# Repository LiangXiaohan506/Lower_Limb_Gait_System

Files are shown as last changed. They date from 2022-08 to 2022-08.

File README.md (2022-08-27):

# Lower_Limb_Gait_System
下肢步态数据采集系统

本项目针对医学康复中的下肢外骨骼步态规划困难、难以实现个性化、控制反馈信息不完善等问题，研发了可穿戴便携式步态数据采集系统。

使用鞋垫形的柔性阵列压力传感器采集静态或运动态的足底压力，使用六轴传感器（3轴陀螺仪+3轴加速度计）采集踝关节、足尖、膝关节、髋关节静态或运动态的关节角度信息。通过优化的并行式采集电路和采集算法，实现压力分布数据的快速采集，采集到的数据可以通过WIFI或串口上传到自主开发的上位机，在上位中进行数据显示和保存。

同时为了穿戴的舒适性，本项目为数据采集模块设计了符合人体工学的外壳。

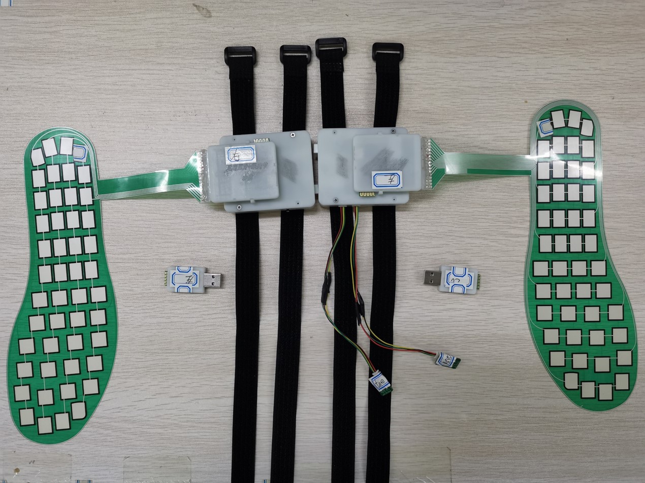
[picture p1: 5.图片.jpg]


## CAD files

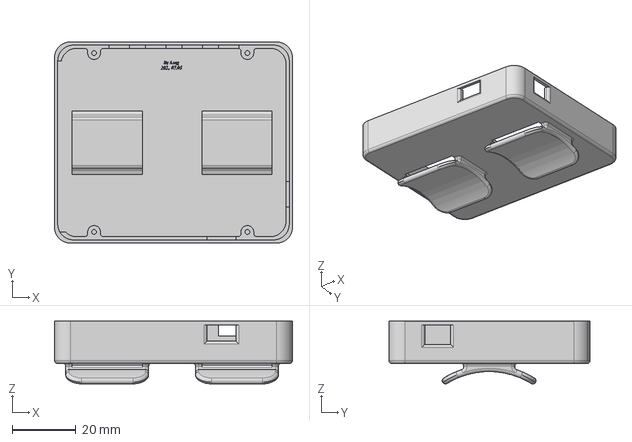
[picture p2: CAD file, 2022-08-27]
3.PP-Model/电源模块-底-V2.0-右.step
74.5 x 63.0 x 19.7 mm

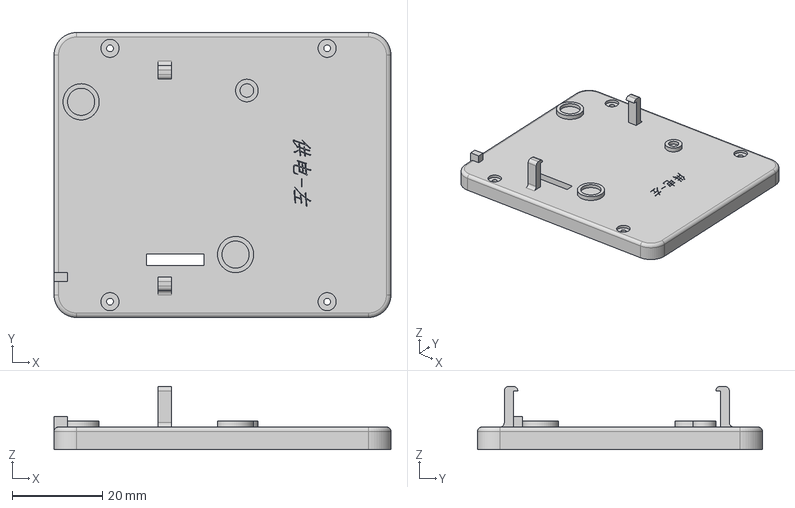
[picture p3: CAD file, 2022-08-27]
3.PP-Model/电源模块-盖-V2.0-左.step
74.5 x 63.0 x 14.0 mm

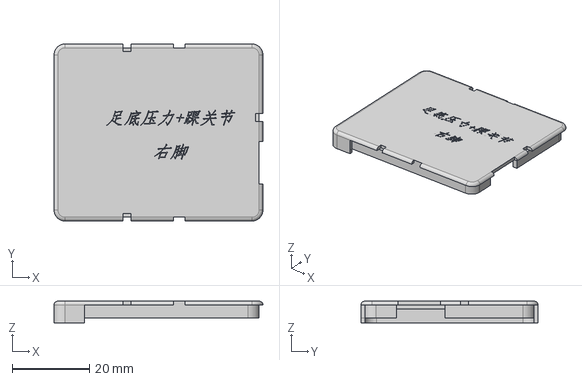
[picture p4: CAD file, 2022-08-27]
3.PP-Model/足底外壳-盖-V2.0-右.step
54.0 x 45.8 x 5.60 mm

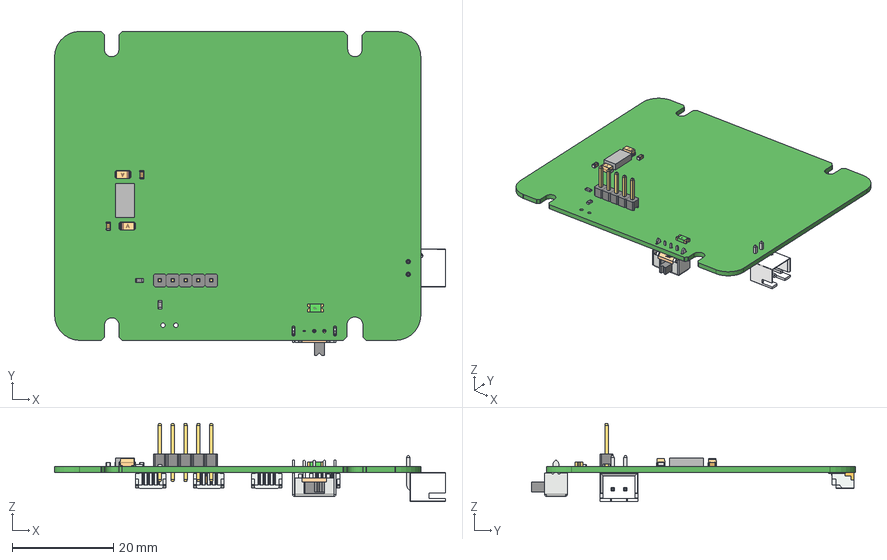
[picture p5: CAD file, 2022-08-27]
3.PP-Model/电源板.step
77.1 x 64.0 x 15.4 mm
Board
Extruded
SK-12D07
LOGO?0.75
R_0603 x 2
LOGO? x 13
SH07W_KORP x 4
SHXX_PIN x 4
SHXX_PIN_1 x 4
SHXX_PIN_2 x 4
SHXX_PIN_4 x 4
SHXX_PIN_5 x 4
SHXX_PIN_6 x 4
HDR2.54-1P x 5
FU_1206
CD_A(3216) x 2
C_0603 x 2
XH2.54-2P_H

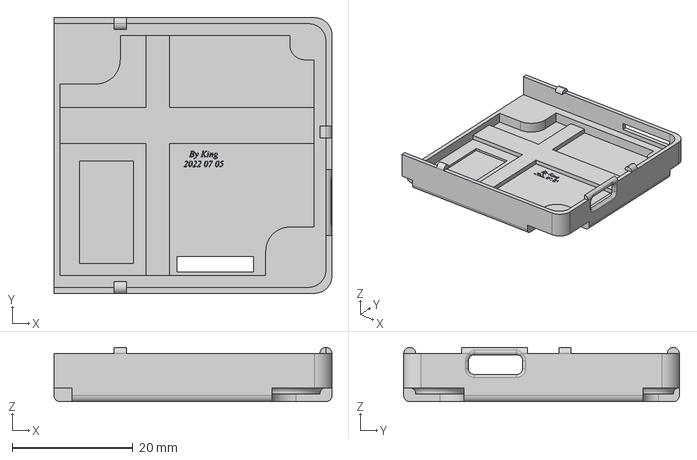
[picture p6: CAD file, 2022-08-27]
3.PP-Model/足底外壳-底-V2.0-左.step
46.1 x 45.8 x 9.00 mm

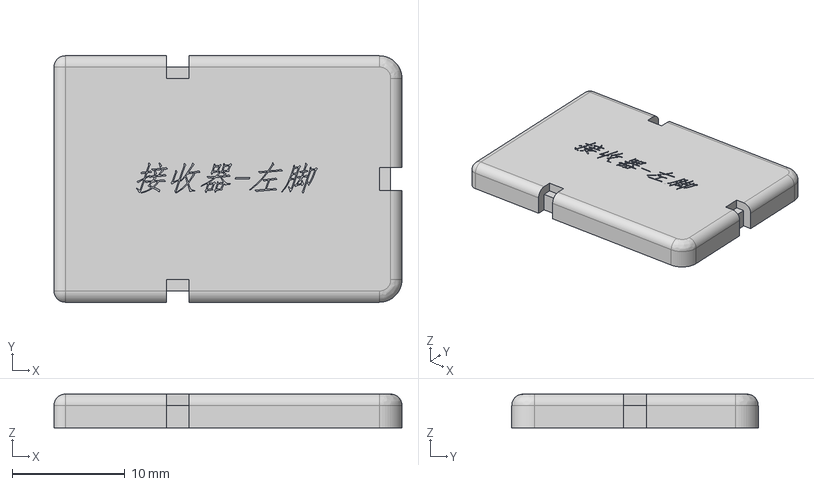
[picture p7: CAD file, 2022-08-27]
3.PP-Model/接收器_盖_左.step
30.9 x 21.9 x 3.00 mm

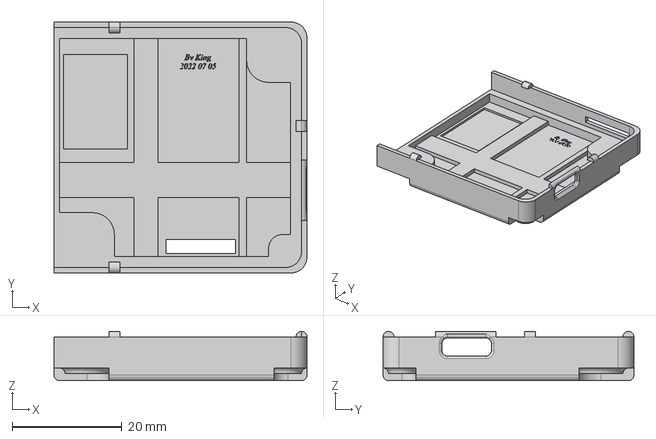
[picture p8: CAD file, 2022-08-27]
3.PP-Model/足底外壳-底-V2.0-右.step
46.1 x 45.8 x 9.00 mm

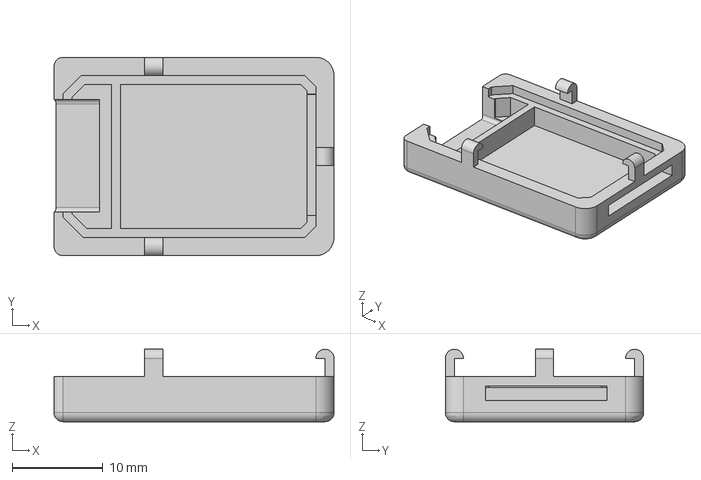
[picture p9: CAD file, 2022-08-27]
3.PP-Model/接收器_底.step
30.9 x 21.9 x 8.00 mm

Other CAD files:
3.PP-Model/足底外壳-盖-V2.0-左.step
3.PP-Model/接收器_盖_右.step
3.PP-Model/电源模块-底-V2.0-左.step
3.PP-Model/电源模块-盖-V2.0-右.step

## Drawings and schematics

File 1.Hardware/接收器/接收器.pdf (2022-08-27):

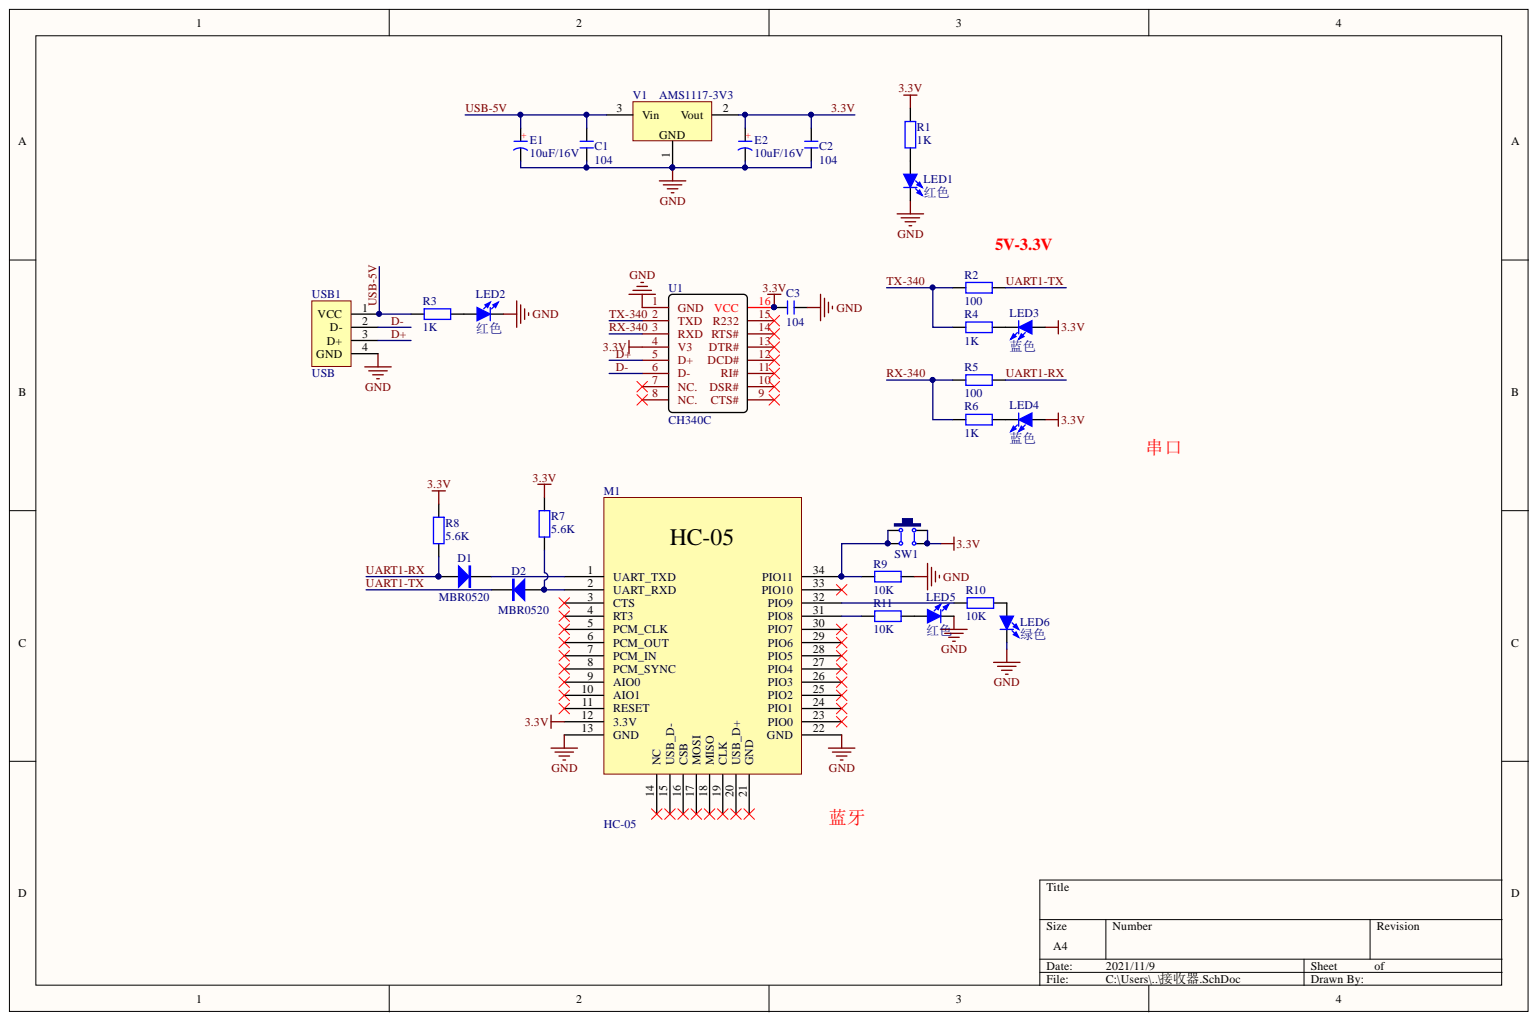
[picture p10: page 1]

UART_RXD 2
RT3 4 | R11

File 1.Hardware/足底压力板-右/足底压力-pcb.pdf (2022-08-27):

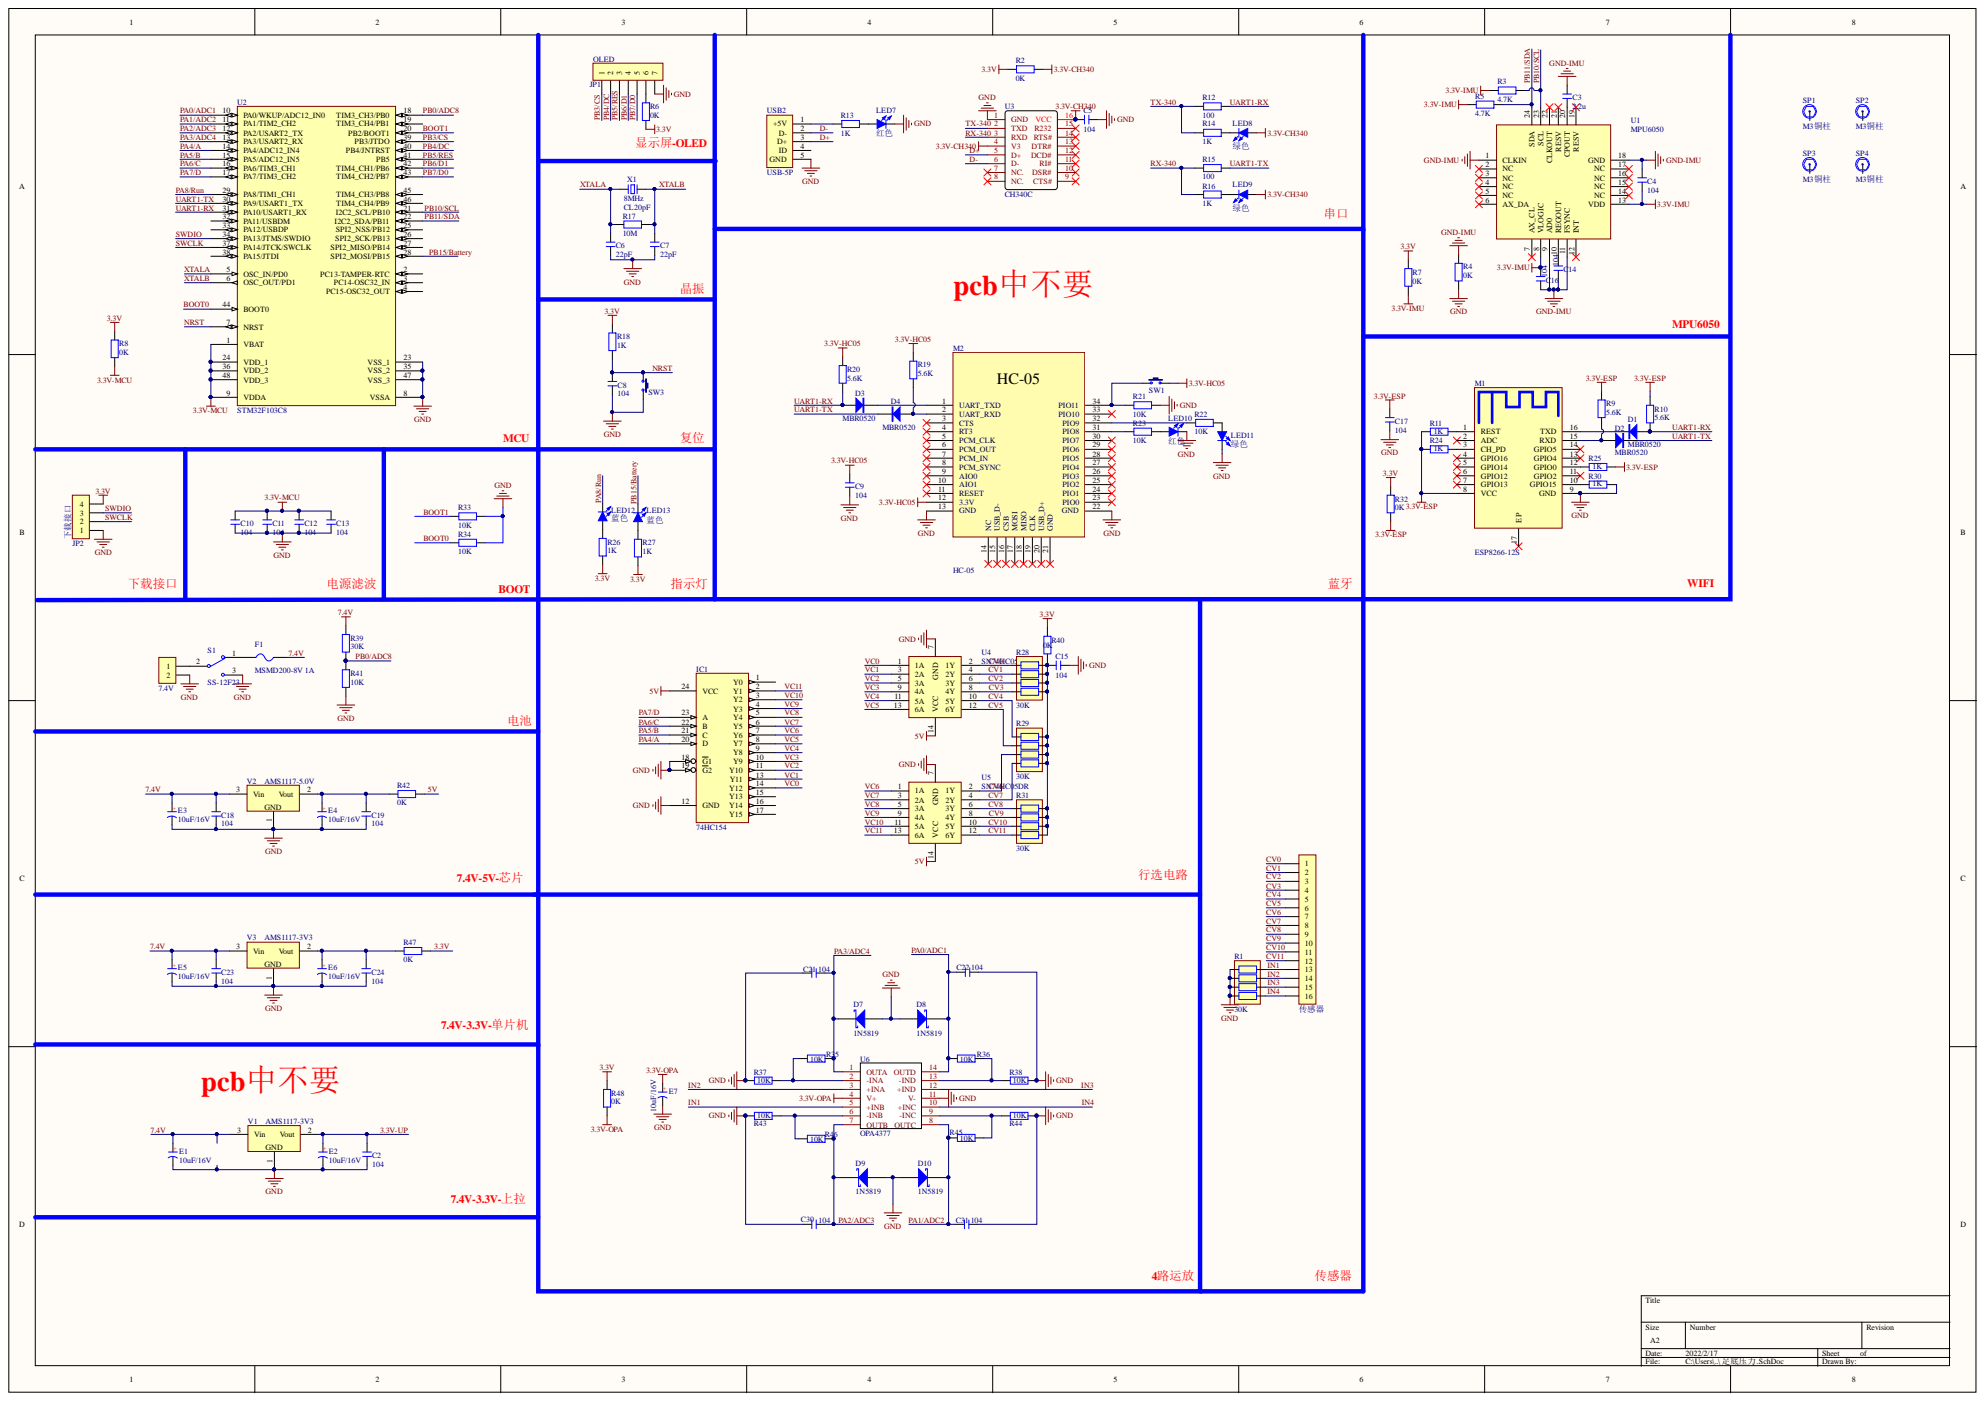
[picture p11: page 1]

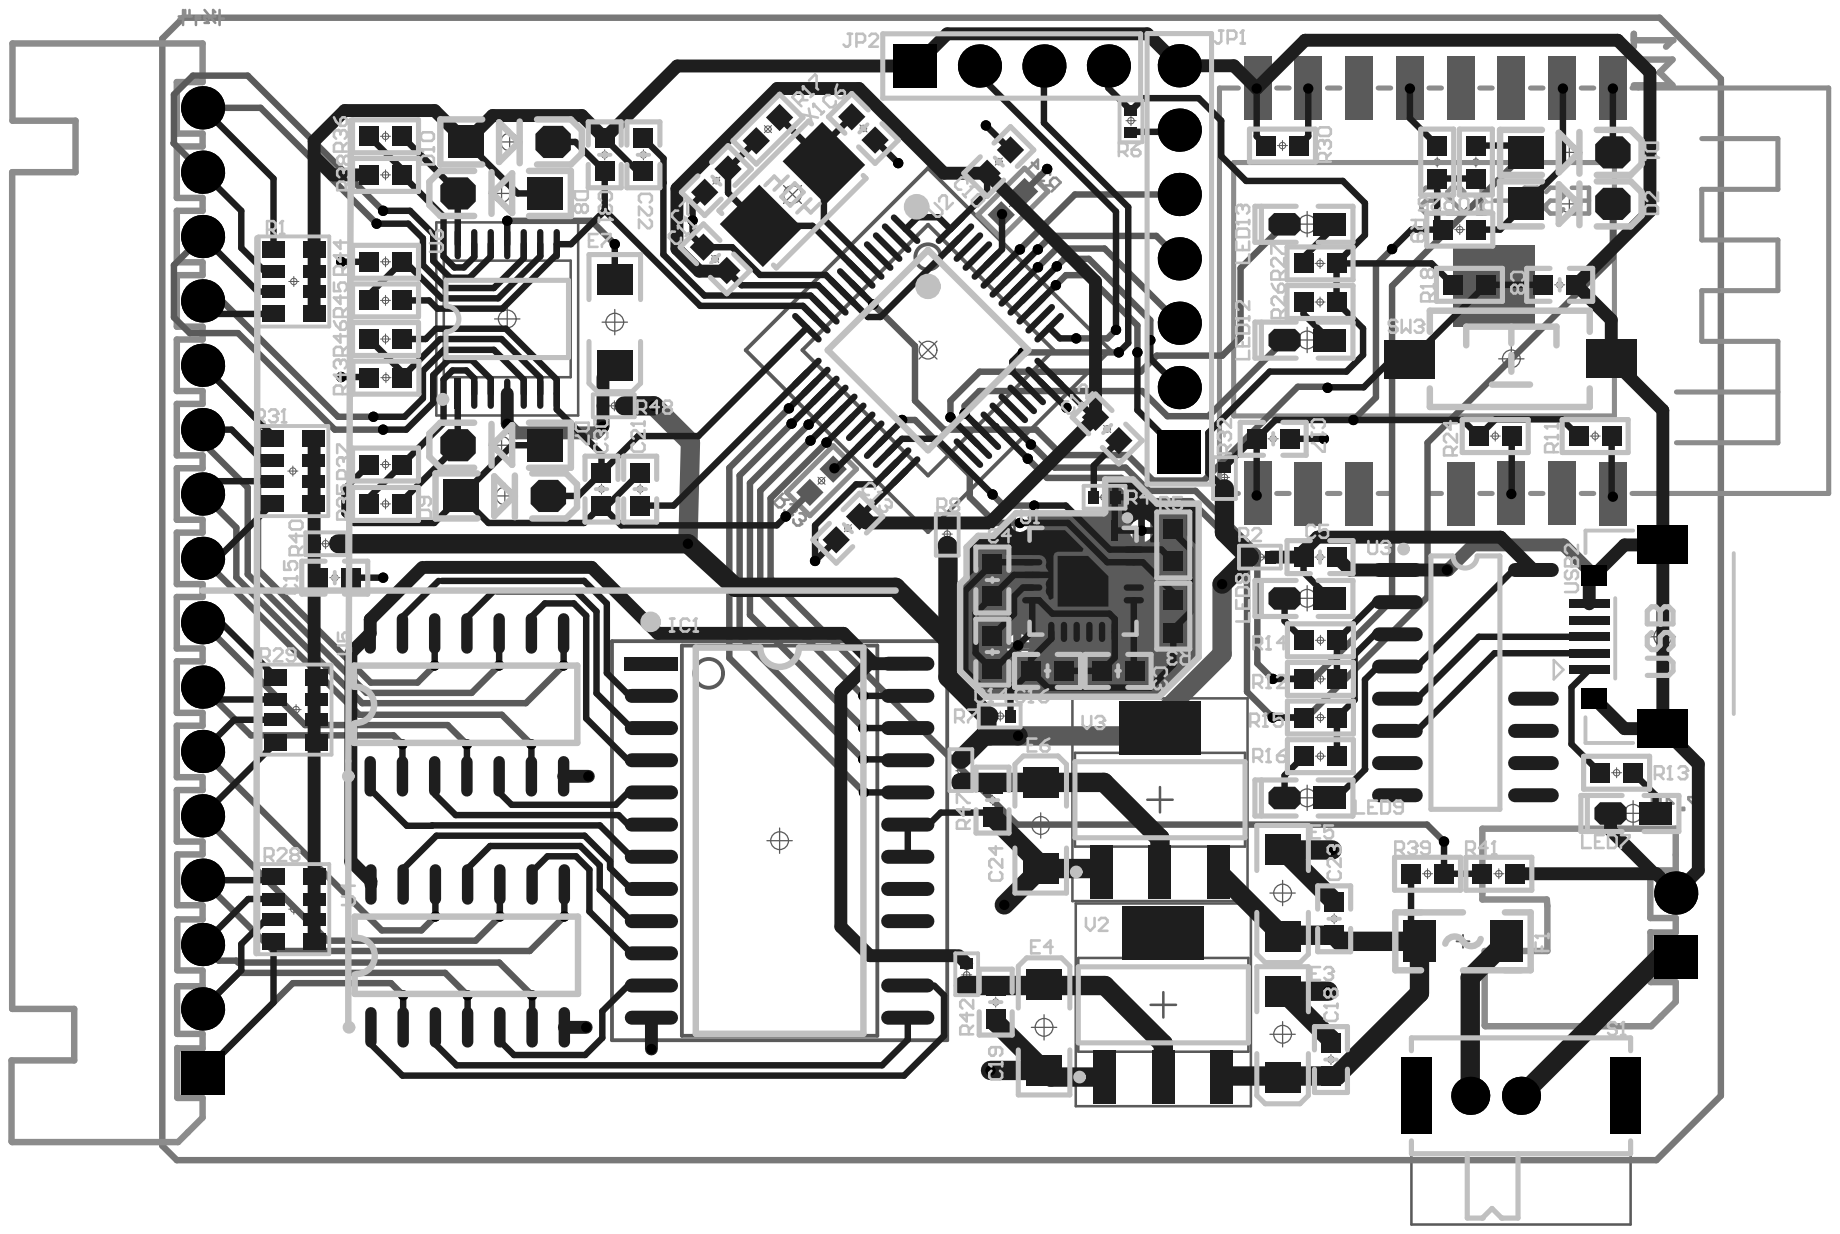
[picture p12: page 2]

Comment | Description | Designator | Footprint | LibRef | Quantity
HDR-1X2 | 2P接插件 | 7.4V | XH2.54-WI-2P | Header 2 | 1
104 | 贴片电容 | C2, C4, C5, C8, C10, C11, C12, C13, C14, C15, C16, C17, C18, C19, C21, C22, C23, C24, C30, C31 | C 0603_L | C | 20
2.2u | 贴片电容 | C3 | C 0603_L | C | 1
22pF | 贴片电容 | C6, C7 | C 0603_L | C | 2
104 | 贴片电容 | C9 | C 0805_L | C | 1
MBR0520 | 整流二极管 | D1, D2, D3, D4 | SOD-123 | 1N4007 | 4
1N5819 | 肖特基二极管 | D7, D8, D9, D10 | SOD-123 | 1N5819 | 4
10uF/16V | 贴片钽电容 | E1, E2, E3, E4, E5, E6, E7 | CD A(3216) | CT | 7
MSMD200-8V 1A | 贴片保险丝 | F1 | FU 1206 | FU | 1
74HC154 | 4线转16线译码器 | IC1 | SOP24_N | 74HC154 | 1
HDR-1X7 | 7P接插件 | JP1 | HDR2.54-M-LI-7P | Header 7 | 1
HDR-1X4 | 4P接插件 | JP2 | HDR2.54-LI-4P | Header 4 | 1
红色 | 贴片LED | LED7 | LED 0603R | LED-SMD | 1
绿色 | 贴片LED | LED8, LED9 | LED 0603G | LED-SMD | 2
红色 | 贴片LED | LED10 | LED 0805R | LED-SMD | 1
绿色 | 贴片LED | LED11 | LED 0805G | LED-SMD | 1
蓝色 | 贴片LED | LED12, LED13 | LED 0603B | LED-SMD | 2
ESP8266-12S | 立创商城 | M1 | ESP8266-12S | ESP8266-12S | 1
HC-05 | 串口蓝牙模块 | M2 | HC-05 | HC-05 | 1
30K | 贴片排阻 | R1, R28, R29, R31 | RCA-8P4R-0603 | R-8P4R | 4
0K | 贴片电阻 | R2, R4, R6, R7, R8, R32, R40, R42, R47, R48 | R 0402_L | R | 10
4.7K | 贴片电阻 | R3, R5 | R 0603_L | R | 2
5.6K | 贴片电阻 | R9, R10 | R 0603_L | R | 2
1K | 贴片电阻 | R11, R13, R14, R16, R18, R24, R25, R26, R27, R30 | R 0603_L | R | 10
100 | 贴片电阻 | R12, R15 | R 0603_L | R | 2
10M | 贴片电阻 | R17 | R 0603_L | R | 1
5.6K | 贴片电阻 | R19, R20 | R 0805_L | R | 2
10K | 贴片电阻 | R21, R22, R23 | R 0805_L | R | 3
10K | 贴片电阻 | R33, R34, R35, R36, R37, R38, R41, R43, R44, R45, R46 | R 0603_L | R | 11
30K | 贴片电阻 | R39 | R 0603_L | R | 1
SS-12F23 | 1路波动开关 | S1 | SK-12D07VG3 | SSW-1P | 1
M3铜柱 | 铜柱 | SP1, SP2, SP3, SP4 | M3x20_L | 铜柱小焊盘 | 4
3x6x5 | 3x6轻触开关 | SW1, SW3 | TSW SMD-3*6*2.5 | TSW 3x6 | 2
MPU6050 | 数字运动传感器 | U1 | QFN24 4x4_L | MPU6050 | 1
STM32F103C8 | Flaah:64/RAM:20/IO: 36 | U2 | LQFP48 7X7_L | STM32F103C8 | 1
CH340C | 串口芯片，无需外部 晶振 | U3 | SOP16 | CH340C | 1
SN74HC05DR | | U4, U5 | SOP14 | SN74HC05DR | 2
OPA4377 | 4路运放 | U6 | TSSOP14_L | OPA4377 | 1
USB-5P | 微型USB母座 | USB2 | USB-MICRO_A | USB-5P | 1
AMS1117-3V3 | 三端稳压芯片 | V1, V3 | SOT223_L | AMS1117 | 2
AMS1117-5.0V | 三端稳压芯片 | V2 | SOT223_L | AMS1117 | 1
8MHz | 2脚无源脚晶振 | X1 | OSC 5032-2P | XTAL-2P | 1
HDR-1X16 | 16P接插件 | 传感器 | XH2.54-WI-16P | Header 16 | 1

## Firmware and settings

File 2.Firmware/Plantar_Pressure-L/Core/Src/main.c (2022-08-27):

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
/* Includes ------------------------------------------------------------------*/
#include "main.h"
#include "adc.h"
#include "can.h"
#include "dma.h"
#include "i2c.h"
#include "tim.h"
#include "usart.h"
#include "gpio.h"

/* USER CODE BEGIN Includes */
#include "mpu6050.h"
#include "inv_mpu.h"
#include "inv_mpu_dmp_motion_driver.h" 
/* USER CODE END Includes */


/* USER CODE BEGIN PV */
volatile float pitch,roll,yaw;//欧拉角
uint8_t uart_buf_imu[6*4];//串口发送陀螺仪数据容器

uint16_t Battery;//电池电压值
uint8_t uart_buf_bat[2];//串口发送电池电压容器

uint16_t ADC_ConvertedValue[4];//DMA存储数据的容器
uint16_t Voltage;//阵列传感器的数据
uint16_t VoltageS[12][4];//阵列传感器的数据
uint8_t Row_list[4] = {0, 1, 2, 3};//列顺序
//******************{6,7,5,8,4,9,3, 10,2, 11,1, 12}
//******************{7,6,8,5,9,4,11,1, 10,2, 13,3}
//******************{6,5,7,4,8,3,10,0, 9, 1, 12,2}
uint8_t Row_A[12] = {0,0,0,0,1,0,1, 0, 1, 0, 1, 0};
uint8_t Row_B[12] = {1,1,1,1,0,0,0, 0, 0, 0, 1, 0};
uint8_t Row_C[12] = {1,0,1,0,0,1,1, 0, 0, 0, 0, 1};
uint8_t Row_D[12] = {0,1,1,0,0,1,0, 0, 1, 1, 0, 0};//1~12
uint8_t uart_buf_v[96];//串口发送阵列电压容器

static CAN_TxHeaderTypeDef        TxMessage;    //CAN发送的消息的消息头
static CAN_RxHeaderTypeDef        RxMessage;    //CAN接收的消息的消息头

extern uint8_t RxBuffer[8];//接收上位机串口数据的缓冲器

uint8_t OrderBuffer[8] = {0x01, 0x02, 0x03, 0x04, 0x05, 0x06, 0x07, 0x08};//设备与上位机之间的命令
uint8_t canOrderBuffer[9] = {0x01, 0x02, 0x03, 0xB1, 0xB2, 0xB3, 0xC1, 0xC2, 0xC3};//主机与从机之间的命令

uint8_t linkOK = 0;//请求连接同意标志位
uint8_t Modes = 0;//发送数据模式，0：电池/停止发送，2：足底+电池，3：角度+电池，4：足底+角度+电池

uint8_t uart_send_buf[130];//数据发送缓冲器

uint8_t up_bat_ones = 1;//读取电池数据间隔时间设置位
uint8_t times_bat;//读取电池数据间隔时间设置位
uint8_t times_up_bat;//读取电池数据间隔时间设置位
uint8_t times_req;//循环发送请求时间间隔设置位

uint8_t toe_slave = 0;//足尖从机在不在的标志位
uint8_t knee_slave = 0;//足尖从机在不在的标志位
uint8_t hip_slave = 0;//足尖从机在不在的标志位

uint8_t slavers_mode = 0;//足尖从机在不在的标志位

uint8_t order_or_data = 0;//主机接收的是命令还是数据

uint8_t imu_collect_over = 0;//从机数据采集结束标志

uint8_t receive_data_over = 0;//从机数据采集结束标志

uint8_t data_test[8];
/* USER CODE END PV */

void SystemClock_Config(void);
/* USER CODE BEGIN PFP */
void usart1_niming_report(uint8_t fun, uint8_t *data, uint8_t len);
void mpu6050_send_data(short roll, short pitch, short yaw);
void Get_Battery(void);
void Get_DMA_ADC1(void);
void delay_us(uint32_t us);
void MPU6050_Get_Data(void);
static void CANFilter_Config(void);
void CAN_Send(uint8_t orderD);
void Upload_Battery(uint8_t *data, uint8_t len);
void Upload_Order(uint8_t data);
void Upload_Data(uint8_t *data, uint8_t len);
void ask_Slavers();
void ask_IPC_Link();
/* USER CODE END PFP */

/**
  * @brief  The application entry point.
  * @retval int
  */
int main(void)
{
  /* MCU Configuration--------------------------------------------------------*/

  /* Reset of all peripherals, Initializes the Flash interface and the Systick. */
  HAL_Init();

  /* Configure the system clock */
  SystemClock_Config();

  /* USER CODE BEGIN SysInit */
	HAL_Delay(500);//软件上电延时，避免ESP上电时对串口中断的影响
  /* USER CODE END SysInit */

  /* Initialize all configured peripherals */
  MX_GPIO_Init();
  MX_USART1_UART_Init();
  MX_DMA_Init();
  MX_ADC1_Init();
  MX_I2C2_Init();
  MX_ADC2_Init();
  MX_TIM1_Init();
  MX_CAN_Init();
  MX_TIM2_Init();
  /* USER CODE BEGIN 2 */
	/* 1. CAN Filter Config */
	CANFilter_Config();
	/* 2. CAN Start */
	if(HAL_CAN_Start(&hcan) != HAL_OK) 
	{
		Error_Handler();
	}
  /* 3. Enable CAN RX Interrupt */
	if(HAL_CAN_ActivateNotification(&hcan, CAN_IT_RX_FIFO0_MSG_PENDING) != HAL_OK) 
	{
		Error_Handler();
	}
	
	MPU_Init();//初始化MPU6050
	while(mpu_dmp_init())
	{
	}//等待mpu_dmp初始化
	
	ask_Slavers();//查询从机的连接情况
	
	ask_IPC_Link();//向上位机发送请求连接命令
	
	Get_Battery();//读取电池电压
	
	uint8_t i;//定义for循环变量
  /* USER CODE END 2 */

  /* Infinite loop */
  /* USER CODE BEGIN WHILE */
  while (1)
  {
		while(!linkOK){times_bat = 0;}//等待连接同意
			
		if(up_bat_ones)//同意连接后发送一次电池电压
		{
			Upload_Battery(uart_buf_bat, 2);
			up_bat_ones = 0;
		}

		switch(Modes)//选择发送模式
		{
			case 2:
				Get_DMA_ADC1();
				Upload_Data(uart_buf_v, 96);
				break;
			case 3:
				if(toe_slave)//如果从机1在
				{
					CAN_Send(canOrderBuffer[6]);//让从机1发送采集结束标志
				}
				else if(knee_slave)//如果从机1不在，从机2在
				{
					CAN_Send(canOrderBuffer[7]);//让从机2发送采集结束标志
				}
				else if(hip_slave)//如果从机1、2不在，从机3在
				{
					CAN_Send(canOrderBuffer[8]);//让从机3发送采集结束标志
				}
				else//如果没有从机连接
				{
					receive_data_over = 1;
				}
				MPU6050_Get_Data();
//				while(!receive_data_over){}//等待从机数据传输完成
				Upload_Data(uart_buf_imu, 6*4);
				receive_data_over = 0;
				break;
			case 4:
				Get_DMA_ADC1();
				if(toe_slave)//如果从机1在
				{
					CAN_Send(canOrderBuffer[6]);//让从机1发送采集结束标志
				}
				else if(knee_slave)//如果从机1不在，从机2在
				{
					CAN_Send(canOrderBuffer[7]);//让从机2发送采集结束标志
				}
				else if(hip_slave)//如果从机1、2不在，从机3在
				{
					CAN_Send(canOrderBuffer[8]);//让从机3发送采集结束标志
				}
				else//如果没有从机连接
				{
					receive_data_over = 1;
				}
				MPU6050_Get_Data();
				while(!receive_data_over){}//等待从机数据传输完成
				for(i=0; i<96; i++)
				{
					uart_send_buf[i] = uart_buf_v[i];
				}
				for(i=0; i<6*4; i++)
				{
					uart_send_buf[96+i] = uart_buf_imu[i];
				}
				Upload_Data(uart_send_buf, 120);
				break;
		}
		
		if(times_up_bat == 6)//每隔一分钟上传一次电池电压
		{
			Battery = (uint16_t)(Battery/6.0);//对一分钟内采集的六次电压取平均值
			uart_buf_bat[0] = Battery>>8;//数据高位
			uart_buf_bat[1] = Battery&0xff;//数据低位
			Upload_Battery(uart_buf_bat, 2);
			times_up_bat = 0;
		}
		
//		Upload_Order(OrderBuffer[0]);
//		HAL_Delay(100);
    /* USER CODE END WHILE */

    /* USER CODE BEGIN 3 */
  }
  /* USER CODE END 3 */
}

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
/* USER CODE BEGIN 4 */
/**
  * @brief 传送数据给匿名四轴上位机软件(V2.6版本)
  * @retval None
	* @fun 功能字. 0XA0~0XAF
	* @data 数据缓存区,最多28字节!!
	* @len data区有效数据个数
	*/
void usart1_niming_report(uint8_t fun, uint8_t *data, uint8_t len)
{
	uint8_t send_buf[32];
	uint8_t imu_data[1];
	uint8_t i;
	if(len>28)return;	//最多28字节数据 
	send_buf[len+3]=0;	//校验数置零
	send_buf[0]=0X88;	//帧头
	send_buf[1]=fun;	//功能字
	send_buf[2]=len;	//数据长度
	for(i=0;i<len;i++)send_buf[3+i]=data[i];			//复制数据
	for(i=0;i<len+3;i++)send_buf[len+3]+=send_buf[i];	//计算校验和	
	for(i=0;i<len+4;i++)
	{
		imu_data[0] = send_buf[i];
		HAL_UART_Transmit(&huart1, imu_data, 1, 2);
	}
}

/**
	*@brief 通过串口1上报结算后的姿态数据给电脑
	*@roll 横滚角.单位0.01度。 -18000 -> 18000 对应 -180.00  ->  180.00度
	*@pitch 俯仰角.单位 0.01度。-9000 - 9000 对应 -90.00 -> 90.00 度
	*@yaw 航向角.单位为0.1度 0 -> 3600  对应 0 -> 360.0度
	*/
void mpu6050_send_data(short roll, short pitch, short yaw)
{
	uint8_t tbuf[6]; 
	
	tbuf[0]=(roll>>8)&0XFF;
	tbuf[1]=roll&0XFF;
	tbuf[2]=(pitch>>8)&0XFF;
	tbuf[3]=pitch&0XFF;
	tbuf[4]=(yaw>>8)&0XFF;
	tbuf[5]=yaw&0XFF; 

	usart1_niming_report(0XA1,tbuf,6);//自定义帧,0XA1
}	

/**
	*@brief 通过ADC2读取电池电压值
  * @retval None
	*/
void Get_Battery(void)
{
	uint16_t Battery_buf = 0;//电池电压值
	HAL_ADC_Start(&hadc2);//启动ADC转换
	HAL_ADC_PollForConversion(&hadc2, 1);//等待转换完成，第二个参数表示超时时间，单位ms.
	if(HAL_IS_BIT_SET(HAL_ADC_GetState(&hadc2), HAL_ADC_STATE_REG_EOC))
	{
		Battery_buf = HAL_ADC_GetValue(&hadc2);//读取ADC转换数据，数据为12位
		Battery_buf = (float)Battery_buf*(3.310/4096)*1000;
		Battery_buf = Battery_buf*4.0+200;
		
		uart_buf_bat[0] = Battery_buf>>8;//数据高位
		uart_buf_bat[1] = Battery_buf&0xff;//数据低位
	}
}

/**
	*@brief 通过ADC1读取读取DMA_AD值
  * @retval None
	*/
void Get_DMA_ADC1(void)
{
	uint8_t r,i,m;
	
	for(r=0; r<12; r++)//行
	{
		HAL_GPIO_WritePin(GPIOA, R_A_Pin, Row_A[r]);
		HAL_GPIO_WritePin(GPIOA, R_B_Pin, Row_B[r]);
		HAL_GPIO_WritePin(GPIOA, R_C_Pin, Row_C[r]);
		HAL_GPIO_WritePin(GPIOA, R_D_Pin, Row_D[r]);
		delay_us(50);
		HAL_ADC_Start_DMA(&hadc1, (uint32_t*)&ADC_ConvertedValue, 4);
		delay_us(50);
		for(i=0;i<4;i++)
		{
			m = Row_list[i];//列顺序
			Voltage = (uint16_t)((float)ADC_ConvertedValue[i]/4096*3.310*1000)%10000;
			VoltageS[r][m] = Voltage;
			
			uart_buf_v[r*8+2*m] = Voltage>>8;//数据高位
			uart_buf_v[r*8+2*m+1] = Voltage&0xff;//数据低位
		}
	}
}

/**
	*@brief 延时函数（单位us）
  * @retval None
	*/
void delay_us(uint32_t us)
{
    uint32_t delay = (HAL_RCC_GetHCLKFreq() / 4000000 * us);
    while (delay--)
	{
		;
	}
}

/**
	*@brief 陀螺仪数据读取
  * @retval None
	*/
void MPU6050_Get_Data(void)
{
	while(mpu_dmp_get_data(&pitch,&roll,&yaw)!=0){ }
	
	uart_buf_imu[0]=(short)pitch>>8;
	uart_buf_imu[1]=(short)pitch&0XFF;
	uart_buf_imu[2]=(short)roll>>8;
	uart_buf_imu[3]=(short)roll&0XFF;
	uart_buf_imu[4]=(short)yaw>>8;
	uart_buf_imu[5]=(short)yaw&0XFF;
}

/**
  * @brief CAN过滤器配置函数（掩码全为零，不进行过滤）
  * @retval None
  */
static void CANFilter_Config(void)
{
    CAN_FilterTypeDef  sFilterConfig;
		uint32_t StdId1 = 0x121;//从机1地址
	  uint32_t StdId2 = 0x122;//从机2地址
	  uint32_t StdId3 = 0x123;//从机3地址
    
    sFilterConfig.FilterBank = 0;                       //CAN过滤器编号，过滤器0
    sFilterConfig.FilterMode = CAN_FILTERMODE_IDLIST;   //CAN过滤器模式，列表模式
    sFilterConfig.FilterScale = CAN_FILTERSCALE_16BIT;  //CAN过滤器尺度，16位
    sFilterConfig.FilterIdHigh = StdId1 << 5;			      //16位下，存储第一个从机的ID
    sFilterConfig.FilterIdLow = StdId2 << 5;					  //16位下，存储第二个从机的ID
    sFilterConfig.FilterMaskIdHigh = StdId3 << 5;			  //16位下，存储第三个从机的ID
    sFilterConfig.FilterMaskIdLow = 0x0000;
    sFilterConfig.FilterFIFOAssignment = 0;				      //报文通过过滤器的匹配后，存储到哪个FIFO
    sFilterConfig.FilterActivation = ENABLE;    		    //激活过滤器
    sFilterConfig.SlaveStartFilterBank = 0;
    
    if (HAL_CAN_ConfigFilter(&hcan, &sFilterConfig) != HAL_OK) {
        Error_Handler();
    }
}

/**
  * @brief CAN发送数据函数
  * @retval None
  */
void CAN_Send(uint8_t orderD)
{
	uint8_t dataO[1];
	dataO[0] = orderD;

	uint32_t TxMailbox;
	TxMessage.IDE = CAN_ID_STD;     //设置ID类型，标准模式
	TxMessage.StdId = 0x111;        //设置ID号，标识符，可进行过滤
	TxMessage.RTR = CAN_RTR_DATA;   //设置传送数据帧
	TxMessage.DLC = 1;              //设置数据长度

	if (HAL_CAN_AddTxMessage(&hcan, &TxMessage, dataO, &TxMailbox) != HAL_OK) 
	{
		Error_Handler();
  }
}

/**
  * @brief CAN接收中断处理函数
  * @retval None
  */
void HAL_CAN_RxFifo0MsgPendingCallback(CAN_HandleTypeDef *hcan)
{
	uint8_t i;
	uint8_t  data[8];
	uint8_t  data_uart[1];
	
	if(HAL_CAN_GetRxMessage(hcan, CAN_RX_FIFO0, &RxMessage, data) == HAL_OK)
	{
		if(!order_or_data)
		{
			switch(data[0])
			{
				case 0xA1:
					toe_slave = 1;
					break;
				case 0xA2:
					knee_slave = 1;
					break;
				case 0xA3:
					hip_slave = 1;
					break;
				case 0xA4:
					imu_collect_over = 1;
					if(toe_slave)//如果从机1在
					{
						CAN_Send(canOrderBuffer[3]);//让从机1发送数据
					}
					else if(knee_slave)//如果从机1不在，从机2在
					{
						CAN_Send(canOrderBuffer[4]);//让从机2发送数据
					}
					else//如果从机1、2不在，从机3在
					{
						CAN_Send(canOrderBuffer[5]);//让从机3发送数据
					}
					order_or_data = 1;//命令传输结束
					break;
			}
		}
		else
		{
			switch(RxMessage.StdId)
			{
				case 0x121://从机1，足尖
					for(i=0; i<6; i++)
					{
						uart_buf_imu[6+i] = data[i];
					}
					if(knee_slave)//从机2在
					{
						CAN_Send(canOrderBuffer[4]);//让从机2发送数据
					}
					else if(hip_slave)//从机2不在，从机3存在
					{
						CAN_Send(canOrderBuffer[5]);//让从机3发送数据
					}
					else//从机2、3不在，则数据传输结束
					{
						receive_data_over = 1;//从机数据传输结束标志位置1
						order_or_data = 0;//数据传输结束
					}
					break;
				case 0x122://从机2，膝关节
					for(i=0; i<6; i++)
					{
						uart_buf_imu[6*2+i] = data[i];
					}
					if(hip_slave)//如果从机3存在
					{
						CAN_Send(canOrderBuffer[5]);//让从机3发送数据
					}
					else//从机3不在，则数据传输结束
					{
						receive_data_over = 1;//从机数据传输结束标志位置1
						order_or_data = 0;//数据传输结束
					}
					break;
				case 0x123://从机3，髋关节
					for(i=0; i<6; i++)
					{
						uart_buf_imu[6*3+i] = data[i];
					}
					receive_data_over = 1;//从机数据传输结束标志位置1
					order_or_data = 0;//数据传输结束
					break;
			}
		}
	}
}

/**
  * @brief 串口接收中断处理函数
  * @retval None
  */
void HAL_UART_RxCpltCallback(UART_HandleTypeDef *huart) 
{
	if(huart -> Instance == USART1) 
	{
		if(RxBuffer[0] == 0XF1)//接收到同意连接命令
		{
			linkOK = 1;
		}
		if(RxBuffer[0] == 0XF2)//接收到发送足底+电池数据命令
		{
			Modes = 2;
		}
		if(RxBuffer[0] == 0XF3)//接收到发送角度+电池数据命令
		{
			Modes = 3;
		}
		if(RxBuffer[0] == 0XF4)//接收到发送足底+角度+电池数据命令
		{
			Modes = 4;
		}
		if(RxBuffer[0] == 0XF5)//接收到停止发送命令
		{
			Modes = 0;
		}
	}
	HAL_UART_Receive_IT(&huart1, RxBuffer, 1);
}

/**
  * @brief 上传电池电压
  * @retval None
	* @data 数据缓存区
	* @len data区有效数据个数
	*/
void Upload_Battery(uint8_t *data, uint8_t len)
{
	uint8_t send_buf[8] = {0};
	uint8_t send_data[2] = {0};
	uint8_t i;

	send_buf[6]=0; //校验数置零

	send_buf[0]=0X88;	 //帧头*************0
	send_buf[1]=0XFF;	 //帧头*************1
	send_buf[2]=0XA1;	 //功能字***********2
	send_buf[3]=2;	   //数据长度*********3

	for(i=0;i<len;i++)send_buf[4+i]=data[i];			    //复制数据
	for(i=0;i<len+4;i++)send_buf[len+4]+=send_buf[i];	//计算校验和	
	
	for(i=0;i<(len+6)/2;i++)
	{
		send_data[0] = send_buf[2*i];
		send_data[1] = send_buf[2*i+1];
		HAL_UART_Transmit(&huart1, send_data, 2, 1);
	}
}

/**
  * @brief 命令上传上位机
  * @retval None
	* @data 数据缓存区
	* @len data区有效数据个数
	*/
void Upload_Order(uint8_t data)
{
	uint8_t send_buf[10] = {0};
	uint8_t i;

	send_buf[5]=0; //校验数置零
	
	send_buf[0]=0X88;	 //帧头*************0
	send_buf[1]=0XFF;	 //帧头*************1
	send_buf[2]=0XA0;	 //功能字***********2
	send_buf[3]=1;	   //数据长度*********3

	send_buf[4]=data;			    //复制数据
	for(i=0;i<5;i++)send_buf[5]+=send_buf[i];	//计算校验和

	HAL_UART_Transmit(&huart1, send_buf, 6, 1);
}

/**
  * @brief 数据上传上位机
  * @retval None
	* @data 数据缓存区
	* @len data区有效数据个数
	*/
void Upload_Data(uint8_t *data, uint8_t len)
{
	uint8_t send_buf[130] = {0};
	uint8_t send_data[2] = {0};
	uint8_t i;

	send_buf[0]=0X88;	 //帧头*************0
	send_buf[1]=0XFF;	 //帧头*************1
	send_buf[2]=0XAF;	 //功能字***********2
	send_buf[3]=len;	 //数据长度*********3

	for(i=0;i<len;i++)send_buf[4+i]=data[i];			    //复制数据
	for(i=0;i<len+4;i++)send_buf[len+4]+=send_buf[i];	//计算校验和	
	
	for(i=0;i<(len+6)/2;i++)
	{
		send_data[0] = send_buf[2*i];
		send_data[1] = send_buf[2*i+1];
		HAL_UART_Transmit(&huart1, send_data, 2, 1);
	}
}

/**
  * @brief 定时器中断处理函数
  * @retval None
  */
void HAL_TIM_PeriodElapsedCallback(TIM_HandleTypeDef *htim)
{
	if(htim == &htim1)
	{
		times_bat++;
		
		if(times_bat == 10)//每10s读取一次电池电压
		{
			uint16_t Battery_buf_tim = 0;//电池电压值
			times_up_bat++;
			
			HAL_ADC_Start(&hadc2);//启动ADC装换
			HAL_ADC_PollForConversion(&hadc2, 1);//等待转换完成，第二个参数表示超时时间，单位ms.
			if(HAL_IS_BIT_SET(HAL_ADC_GetState(&hadc2), HAL_ADC_STATE_REG_EOC))
			{
				Battery_buf_tim = HAL_ADC_GetValue(&hadc2);//读取ADC转换数据，数据为12位
				Battery_buf_tim = (float)Battery_buf_tim*(3.310/4096)*1000;
				Battery_buf_tim = Battery_buf_tim*4.0+200;
				
				Battery = Battery+Battery_buf_tim;
			}
			times_bat = 0;
		}
	}
	
	if(htim == &htim2)
	{
		times_req++;
		
		if(linkOK)
		{
			HAL_TIM_Base_Stop_IT(&htim2);
		}
		
		if((times_req==2)&(!linkOK))//每2s发送一次请求
		{
			ask_IPC_Link();//发送请求连接命令
			times_req = 0;
		}
	}
}


/**
  * @brief 查询从机的连接情况，有几个从机连接,从机连接组合方式
  * @retval None
  */
void ask_Slavers()
{
	CAN_Send(canOrderBuffer[0]);//询问从机1
	HAL_Delay(10);//等待从机1的回答
	CAN_Send(canOrderBuffer[1]);//询问从机2
	HAL_Delay(10);//等待从机2的回答
	CAN_Send(canOrderBuffer[2]);//询问从机3
	HAL_Delay(10);//等待从机3的回答
	
	slavers_mode = toe_slave + knee_slave*10 + hip_slave*100;//计算从机连接情况
}

/**
  * @brief 向上位机发送请求连接命令
  * @retval None
  */
void ask_IPC_Link()
{
	switch(slavers_mode)
	{
		case 0:
			Upload_Order(OrderBuffer[0]);
			break;
		case 1:
			Upload_Order(OrderBuffer[1]);
			break;
		case 10:
			Upload_Order(OrderBuffer[5]);
			break;
		case 11:
			Upload_Order(OrderBuffer[2]);
			break;
		case 100:
			Upload_Order(OrderBuffer[7]);
			break;
		case 101:
			Upload_Order(OrderBuffer[3]);
			break;
		case 110:
			Upload_Order(OrderBuffer[6]);
			break;
		case 111:
			Upload_Order(OrderBuffer[4]);
			break;
	}
}
/* USER CODE END 4 */
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


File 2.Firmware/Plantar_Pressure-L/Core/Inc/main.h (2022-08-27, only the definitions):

#define R_A_Pin GPIO_PIN_4
#define R_A_GPIO_Port GPIOA
#define R_B_Pin GPIO_PIN_5
#define R_B_GPIO_Port GPIOA
#define R_C_Pin GPIO_PIN_6
#define R_C_GPIO_Port GPIOA
#define R_D_Pin GPIO_PIN_7
#define R_D_GPIO_Port GPIOA
#define Battery_Pin GPIO_PIN_0
#define Battery_GPIO_Port GPIOB

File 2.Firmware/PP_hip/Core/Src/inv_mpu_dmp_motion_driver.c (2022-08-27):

/*
 $License:
    Copyright (C) 2011-2012 InvenSense Corporation, All Rights Reserved.
    See included License.txt for License information.
 $
 */
/**
 *  @addtogroup  DRIVERS Sensor Driver Layer
 *  @brief       Hardware drivers to communicate with sensors via I2C.
 *
 *  @{
 *      @file       inv_mpu_dmp_motion_driver.c
 *      @brief      DMP image and interface functions.
 *      @details    All functions are preceded by the dmp_ prefix to
 *                  differentiate among MPL and general driver function calls.
 */
#include <stdio.h>
#include <stdint.h>
#include <stdlib.h>
#include <string.h>
#include <math.h>
#include "inv_mpu.h"
#include "inv_mpu_dmp_motion_driver.h"
#include "dmpKey.h"
#include "dmpmap.h"


//定义目标板采用MSP430
#define  MOTION_DRIVER_TARGET_MSP430

/* The following functions must be defined for this platform:
 * i2c_write(unsigned char slave_addr, unsigned char reg_addr,
 *      unsigned char length, unsigned char const *data)
 * i2c_read(unsigned char slave_addr, unsigned char reg_addr,
 *      unsigned char length, unsigned char *data)
 * delay_ms(unsigned long num_ms)
 * get_ms(unsigned long *count)
 */
#if defined MOTION_DRIVER_TARGET_MSP430
//#include "msp430.h"
//#include "msp430_clock.h"
#define delay_ms    HAL_Delay
#define get_ms      mget_ms
#define log_i 		  printf
#define log_e  		  printf

#elif defined EMPL_TARGET_MSP430
#include "msp430.h"
#include "msp430_clock.h"
#include "log.h"
#define delay_ms    msp430_delay_ms
#define get_ms      msp430_get_clock_ms
#define log_i       MPL_LOGI
#define log_e       MPL_LOGE

#elif defined EMPL_TARGET_UC3L0
/* Instead of using the standard TWI driver from the ASF library, we're using
 * a TWI driver that follows the slave address + register address convention.
 */
#include "delay.h"
#include "sysclk.h"
#include "log.h"
#include "uc3l0_clock.h"
/* delay_ms is a function already defined in ASF. */
#define get_ms  uc3l0_get_clock_ms
#define log_i       MPL_LOGI
#define log_e       MPL_LOGE

#else
#error  Gyro driver is missing the system layer implementations.
#endif

/* These defines are copied from dmpDefaultMPU6050.c in the general MPL
 * releases. These defines may change for each DMP image, so be sure to modify
 * these values when switching to a new image.
 */
#define CFG_LP_QUAT             (2712)
#define END_ORIENT_TEMP         (1866)
#define CFG_27                  (2742)
#define CFG_20                  (2224)
#define CFG_23                  (2745)
#define CFG_FIFO_ON_EVENT       (2690)
#define END_PREDICTION_UPDATE   (1761)
#define CGNOTICE_INTR           (2620)
#define X_GRT_Y_TMP             (1358)
#define CFG_DR_INT              (1029)
#define CFG_AUTH                (1035)
#define UPDATE_PROP_ROT         (1835)
#define END_COMPARE_Y_X_TMP2    (1455)
#define SKIP_X_GRT_Y_TMP        (1359)
#define SKIP_END_COMPARE        (1435)
#define FCFG_3                  (1088)
#define FCFG_2                  (1066)
#define FCFG_1                  (1062)
#define END_COMPARE_Y_X_TMP3    (1434)
#define FCFG_7                  (1073)
#define FCFG_6                  (1106)
#define FLAT_STATE_END          (1713)
#define SWING_END_4             (1616)
#define SWING_END_2             (1565)
#define SWING_END_3             (1587)
#define SWING_END_1             (1550)
#define CFG_8                   (2718)
#define CFG_15                  (2727)
#define CFG_16                  (2746)
#define CFG_EXT_GYRO_BIAS       (1189)
#define END_COMPARE_Y_X_TMP     (1407)
#define DO_NOT_UPDATE_PROP_ROT  (1839)
#define CFG_7                   (1205)
#define FLAT_STATE_END_TEMP     (1683)
#define END_COMPARE_Y_X         (1484)
#define SKIP_SWING_END_1        (1551)
#define SKIP_SWING_END_3        (1588)
#define SKIP_SWING_END_2        (1566)
#define TILTG75_START           (1672)
#define CFG_6                   (2753)
#define TILTL75_END             (1669)
#define END_ORIENT              (1884)
#define CFG_FLICK_IN            (2573)
#define TILTL75_START           (1643)
#define CFG_MOTION_BIAS         (1208)
#define X_GRT_Y                 (1408)
#define TEMPLABEL               (2324)
#define CFG_ANDROID_ORIENT_INT  (1853)
#define CFG_GYRO_RAW_DATA       (2722)
#define X_GRT_Y_TMP2            (1379)

#define D_0_22                  (22+512)
#define D_0_24                  (24+512)

#define D_0_36                  (36)
#define D_0_52                  (52)
#define D_0_96                  (96)
#define D_0_104                 (104)
#define D_0_108                 (108)
#define D_0_163                 (163)
#define D_0_188                 (188)
#define D_0_192                 (192)
#define D_0_224                 (224)
#define D_0_228                 (228)
#define D_0_232                 (232)
#define D_0_236                 (236)

#define D_1_2                   (256 + 2)
#define D_1_4                   (256 + 4)
#define D_1_8                   (256 + 8)
#define D_1_10                  (256 + 10)
#define D_1_24                  (256 + 24)
#define D_1_28                  (256 + 28)
#define D_1_36                  (256 + 36)
#define D_1_40                  (256 + 40)
#define D_1_44                  (256 + 44)
#define D_1_72                  (256 + 72)
#define D_1_74                  (256 + 74)
#define D_1_79                  (256 + 79)
#define D_1_88                  (256 + 88)
#define D_1_90                  (256 + 90)
#define D_1_92                  (256 + 92)
#define D_1_96                  (256 + 96)
#define D_1_98                  (256 + 98)
#define D_1_106                 (256 + 106)
#define D_1_108                 (256 + 108)
#define D_1_112                 (256 + 112)
#define D_1_128                 (256 + 144)
#define D_1_152                 (256 + 12)
#define D_1_160                 (256 + 160)
#define D_1_176                 (256 + 176)
#define D_1_178                 (256 + 178)
#define D_1_218                 (256 + 218)
#define D_1_232                 (256 + 232)
#define D_1_236                 (256 + 236)
#define D_1_240                 (256 + 240)
#define D_1_244                 (256 + 244)
#define D_1_250                 (256 + 250)
#define D_1_252                 (256 + 252)
#define D_2_12                  (512 + 12)
#define D_2_96                  (512 + 96)
#define D_2_108                 (512 + 108)
#define D_2_208                 (512 + 208)
#define D_2_224                 (512 + 224)
#define D_2_236                 (512 + 236)
#define D_2_244                 (512 + 244)
#define D_2_248                 (512 + 248)
#define D_2_252                 (512 + 252)
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

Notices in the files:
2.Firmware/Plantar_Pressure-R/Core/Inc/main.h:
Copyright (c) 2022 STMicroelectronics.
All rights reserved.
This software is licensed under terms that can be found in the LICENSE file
